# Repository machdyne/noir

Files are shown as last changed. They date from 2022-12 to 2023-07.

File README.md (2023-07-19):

# Noir Computer

Noir is an FPGA computer designed by Lone Dynamics Corporation.

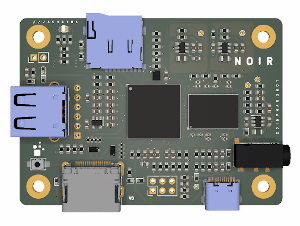
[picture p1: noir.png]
Noir Computer


This repo contains schematics, PCB layouts, pinouts, a 3D-printable case, example gateware and documentation.

Find more information on the [Noir product page](https://machdyne.com/product/noir-computer/).

## Dual-Core Bitstream

There is now a dual-core bitstream optimized for speed that significantly decreases boot time and adds a second RISC-V core.

In addition to updating to this bitstream (`images/v0/noir_dual.bit`), make sure you copy the `images/linux/noir_dual.dtb` file to the SD card and update `boot.json` to use `noir_dual.dtb`.

## Programming Noir

Noir has a JTAG interface and ships with a [DFU bootloader](https://github.com/machdyne/tinydfu-bootloader) that allows the included flash [MMOD](https://machdyne.com/product/mmod) to be programmed over the USB-C port.

### DFU

The DFU bootloader is available for 5 seconds after power-on, issuing a DFU command during this period will stop the boot process until the DFU device is detached. If no command is received the boot process will continue and the user gateware will be loaded.

Install [dfu-util](http://dfu-util.sourceforge.net) (Debian/Ubuntu):

```
$ sudo apt install dfu-util
```

Update the user gateware on the flash MMOD:

```
$ sudo dfu-util -a 0 -D image.bit
```

Detach the DFU device and continue the boot process:

```
$ sudo dfu-util -a 0 -e
```

It is possible to update the bootloader itself using DFU but you shouldn't attempt this unless you have a JTAG programmer (or another method to program the MMOD) available, in case you need to restore the bootloader.

### JTAG

These examples assume you're using a "USB Blaster" JTAG cable, see the header pinout below. You will need to have [openFPGALoader](https://github.com/trabucayre/openFPGALoader) installed.

Program the configuration SRAM:

```
openFPGALoader -c usb-blaster image.bit
```

Program the flash MMOD:

```
openFPGALoader -f -c usb-blaster images/bootloader/tinydfu_noir.bit
```

## Blinky 

Building the blinky example requires [Yosys](https://github.com/YosysHQ/yosys), [nextpnr-ecp5](https://github.com/YosysHQ/nextpnr) and [Project Trellis](https://github.com/YosysHQ/prjtrellis).

Assuming they are installed, you can simply type `make` to build the gateware, which will be written to output/blinky.bin. You can then use [openFPGALoader](https://github.com/trabucayre/openFPGALoader) or dfu-util to write the gateware to the device.

## Linux

See the [Kakao Linux](https://github.com/machdyne/kakao) repo for the latest instructions.

### Prebuilt Images

Copy the files from the `images/linux` directory to the root directory of a FAT-formatted MicroSD card.

Noir ships with LiteX gateware on the user gateware section of the MMOD that is compatible with these images. After several seconds the Linux penguin should appear on the screen (HDMI) followed by a login prompt.

### Building Linux

Please follow the setup instructions in the [linux-on-litex-vexriscv](https://github.com/litex-hub/linux-on-litex-vexriscv) repo and then:

1. Build the Linux-capable gateware:

```
$ cd linux-on-litex-vexriscv
$ ./make.py --board noir --uart-baudrate 115200 --build

$ ls build/noir
```

2. Write the gateware to the MMOD using USB DFU:

```
$ sudo dfu-util -a 0 -D build/noir/gateware/noir.bit
```

3. Copy the device tree binary `build/noir/noir.dtb` to a FAT-formatted MicroSD card.

4. Build the Linux kernel and root filesystem:

```
$ cd ..
$ git clone http://github.com/buildroot/buildroot
$ cd buildroot
$ make BR2_EXTERNAL=../linux-on-litex-vexriscv/buildroot/ litex_vexriscv_usbhost_defconfig
```

Optionally customize the kernel and buildroot packages:

```
$ make menuconfig
```

Build the kernel and rootfs:

```
$ make
$ ls output/images
```

5. Copy the `Image` and `rootfs.cpio` files from output/images to the MicroSD card.

6. Copy the OpenSBI binary (included in this repo as `noir/images/linux/opensbi.bin`) to the MicroSD card. Alternatively, you can build this binary by following [these instructions](https://github.com/litex-hub/linux-on-litex-vexriscv#-generating-the-opensbi-binary-optional).

7. Copy `noir/images/linux/boot.json` to the MicroSD card.

8. Power-cycle Noir. After Linux has finished booting you should see a login prompt on the HDMI display.

## LiteX

### Installing LiteX

If you haven't yet installed LiteX please see the [LiteX quick start guide](https://github.com/enjoy-digital/litex#quick-start-guide) for details on installing LiteX.

### Building Custom Gateware

Build the LiteX gateware:

```
$ cd litex-boards/litex_boards/targets
$ ./machdyne_noir.py --cpu-type=vexriscv --cpu-variant=lite --sys-clk-freq 40000000 --uart-baudrate 1000000 --uart-name serial --build
```

Program the LiteX gateware to SRAM over JTAG:

```
$ ./machdyne_noir.py --cable usb-blaster --load
```

Or program the LiteX gateware to flash over DFU:

```
$ sudo dfu-util -a 0 -D build/machdyne_noir/gateware/machdyne_noir.bit
```

## JTAG Header

The 3.3V JTAG header can be used to program the FPGA SRAM as well as the MMOD flash memory. It can also be used to provide power (5V) to the board.

```
1 2
3 4
5 6
```

| Pin | Signal |
| --- | --- |
| 1 | TCK |
| 2 | TDI |
| 3 | TDO |
| 4 | TMS |
| 5 | 5V0 |
| 6 | GND |

## Resources

 * [fpga-dac audio player](https://github.com/machdyne/fpga-dac)

## Board Revisions

| Revision | Notes |
| --- | ----- |
| V0 | Initial version |
| V1 | Work in progress; adds composite video DAC output to 3.5mm jack |

## License

The contents of this repo are released under the [Lone Dynamics Open License](LICENSE.md) with the following exceptions:

- The KiCad design files contain parts of the [kicad-pmod](https://github.com/mithro/kicad-pmod) library which is released under the [Apache License, Version 2.0](https://www.apache.org/licenses/LICENSE-2.0.html).

- The KiCad design files may contain symbols and footprints released under other licenses; please contact us if we've failed to give proper attribution.

Note: You can use these designs for commercial purposes but we ask that instead of producing exact clones, that you either replace our trademarks and logos with your own or add your own next to ours.

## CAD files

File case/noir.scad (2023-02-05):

/*
 * Noir Case
 * Copyright (c) 2022 Lone Dynamics Corporation. All rights reserved.
 *
 * required hardware:
 *  - 4 x M3 x 18mm countersunk bolts
 *  - 4 x M3 nuts
 *
 */

$fn = 100;

board_width = 50;
board_thickness = 1.5;
board_length = 70;
board_height = 1.6;
board_spacing = 2;

wall = 1.5;

top_height = 10;
bottom_height = 8.5;

mdn_board();

translate([0,0,15])
	mdn_case_top();

translate([0,0,-15])
	mdn_case_bottom();

module mdn_board() {
	
	difference() {
		color([0,0.5,0])
			roundedcube(board_width,board_length,board_thickness,3);
		translate([5, 5, -1]) cylinder(d=3.2, h=10);
		translate([5, 65, -1]) cylinder(d=3.2, h=10);
		translate([45, 5, -1]) cylinder(d=3.2, h=10);
		translate([45, 65, -1]) cylinder(d=3.2, h=10);
	}	
	
}

module mdn_case_top() {
	
	difference() {
				
		color([0.5,0.5,0.5])
			roundedcube(board_width+(wall*2),board_length+(wall*2),top_height,2.5);

		// cutouts
			
		translate([2,9.5,-2])
			roundedcube(board_width-1.25,board_length-16,10.25,2.5);

		translate([9.5,3,-2])
			roundedcube(board_width-16,board_length-3,10.25,2.5);
		
		// led vent
		translate([-1,board_length-59,3.5])
			cube([board_width-10,1.5,1.5]);
	
		translate([wall, wall, 0]) {

			// vents
			translate([50/2-(20/2),60,0]) cube([20,1,20]);
			translate([50/2-(20/2),55,0]) cube([20,1,20]);
			translate([50/2-(20/2),50,0]) cube([20,1,20]);
			
			// HDMI
			translate([30,19.55-(15.5/2),-1]) cube([30,15.5,6.2+1]);
		
			// USBA
			translate([25-(15/2),-5,-1]) cube([15,30,7.2+1]);

			// USBC
			translate([30,53.8-(9.5/2),-1]) cube([30,9.5,3.5+1]);
		
			// SD
			translate([-5,25.3-(15/2),-1]) cube([30,15,2+1]);

			// USBA
			translate([36.5-(6.2/2),65,-1]) cube([6.2,30,5+1]);
			
			// bolt holes
			translate([5, 5, -21]) cylinder(d=3.5, h=40);
			translate([5, 65, -21]) cylinder(d=3.5, h=40);
			translate([45, 5, -20]) cylinder(d=3.5, h=40);
			translate([45, 65, -21]) cylinder(d=3.5, h=40);

			// flush mount bolt holes
			translate([5, 5, top_height-1.5]) cylinder(d=5.25, h=4);
			translate([5, 65, top_height-1.5]) cylinder(d=5.25, h=4);
			translate([45, 5, top_height-1.5]) cylinder(d=5.25, h=4);
			translate([45, 65, top_height-1.5]) cylinder(d=5.25, h=4);

			// noir text
			rotate(270)
				translate([-22.5,25-3,top_height-0.5])
					linear_extrude(1)
						text("N   O   I   R", size=5, halign="center",
							font="Ubuntu:style=Bold");

		}
		
	}	
}

module mdn_case_bottom() {
	
	difference() {
		color([0.5,0.5,0.5])
			roundedcube(board_width+(wall*2),board_length+(wall*2),bottom_height,2.5);
		
		// cutouts
		translate([3,10,1.5])
			roundedcube(board_width-3,board_length-17,10,2.5);
				
		translate([10.5,2.5,1.5])
			roundedcube(board_width-17.5,board_length-2,10,2.5);

		translate([wall, wall, 0]) {
			
		// board cutout
		translate([0,0,bottom_height-board_height])
			roundedcube(board_width+0.2,board_length+0.2,board_height+1,2.5);

		translate([wall, wall, 0]) {

			// USBC
			translate([38.5,53.8-(9.5/2),5]) cube([10,9.5,10.5+1]);
			
		}

		// bolt holes
		translate([5, 5, -11]) cylinder(d=3.2, h=25);
		translate([5, 65, -11]) cylinder(d=3.2, h=25);
		translate([45, 5, -11]) cylinder(d=3.2, h=25);
		translate([45, 65, -11]) cylinder(d=3.2, h=25);

		// nut holes
		translate([5, 5, -1]) cylinder(d=7, h=4, $fn=6);
		translate([5, 65, -1]) cylinder(d=7, h=4, $fn=6);
		translate([45, 5, -1]) cylinder(d=7, h=4, $fn=6);
		translate([45, 65, -1]) cylinder(d=7, h=4, $fn=6);

		}
		
	}	
}

// https://gist.github.com/tinkerology/ae257c5340a33ee2f149ff3ae97d9826
module roundedcube(xx, yy, height, radius)
{
    translate([0,0,height/2])
    hull()
    {
        translate([radius,radius,0])
        cylinder(height,radius,radius,true);

        translate([xx-radius,radius,0])
        cylinder(height,radius,radius,true);

        translate([xx-radius,yy-radius,0])
        cylinder(height,radius,radius,true);

        translate([radius,yy-radius,0])
        cylinder(height,radius,radius,true);
    }
}

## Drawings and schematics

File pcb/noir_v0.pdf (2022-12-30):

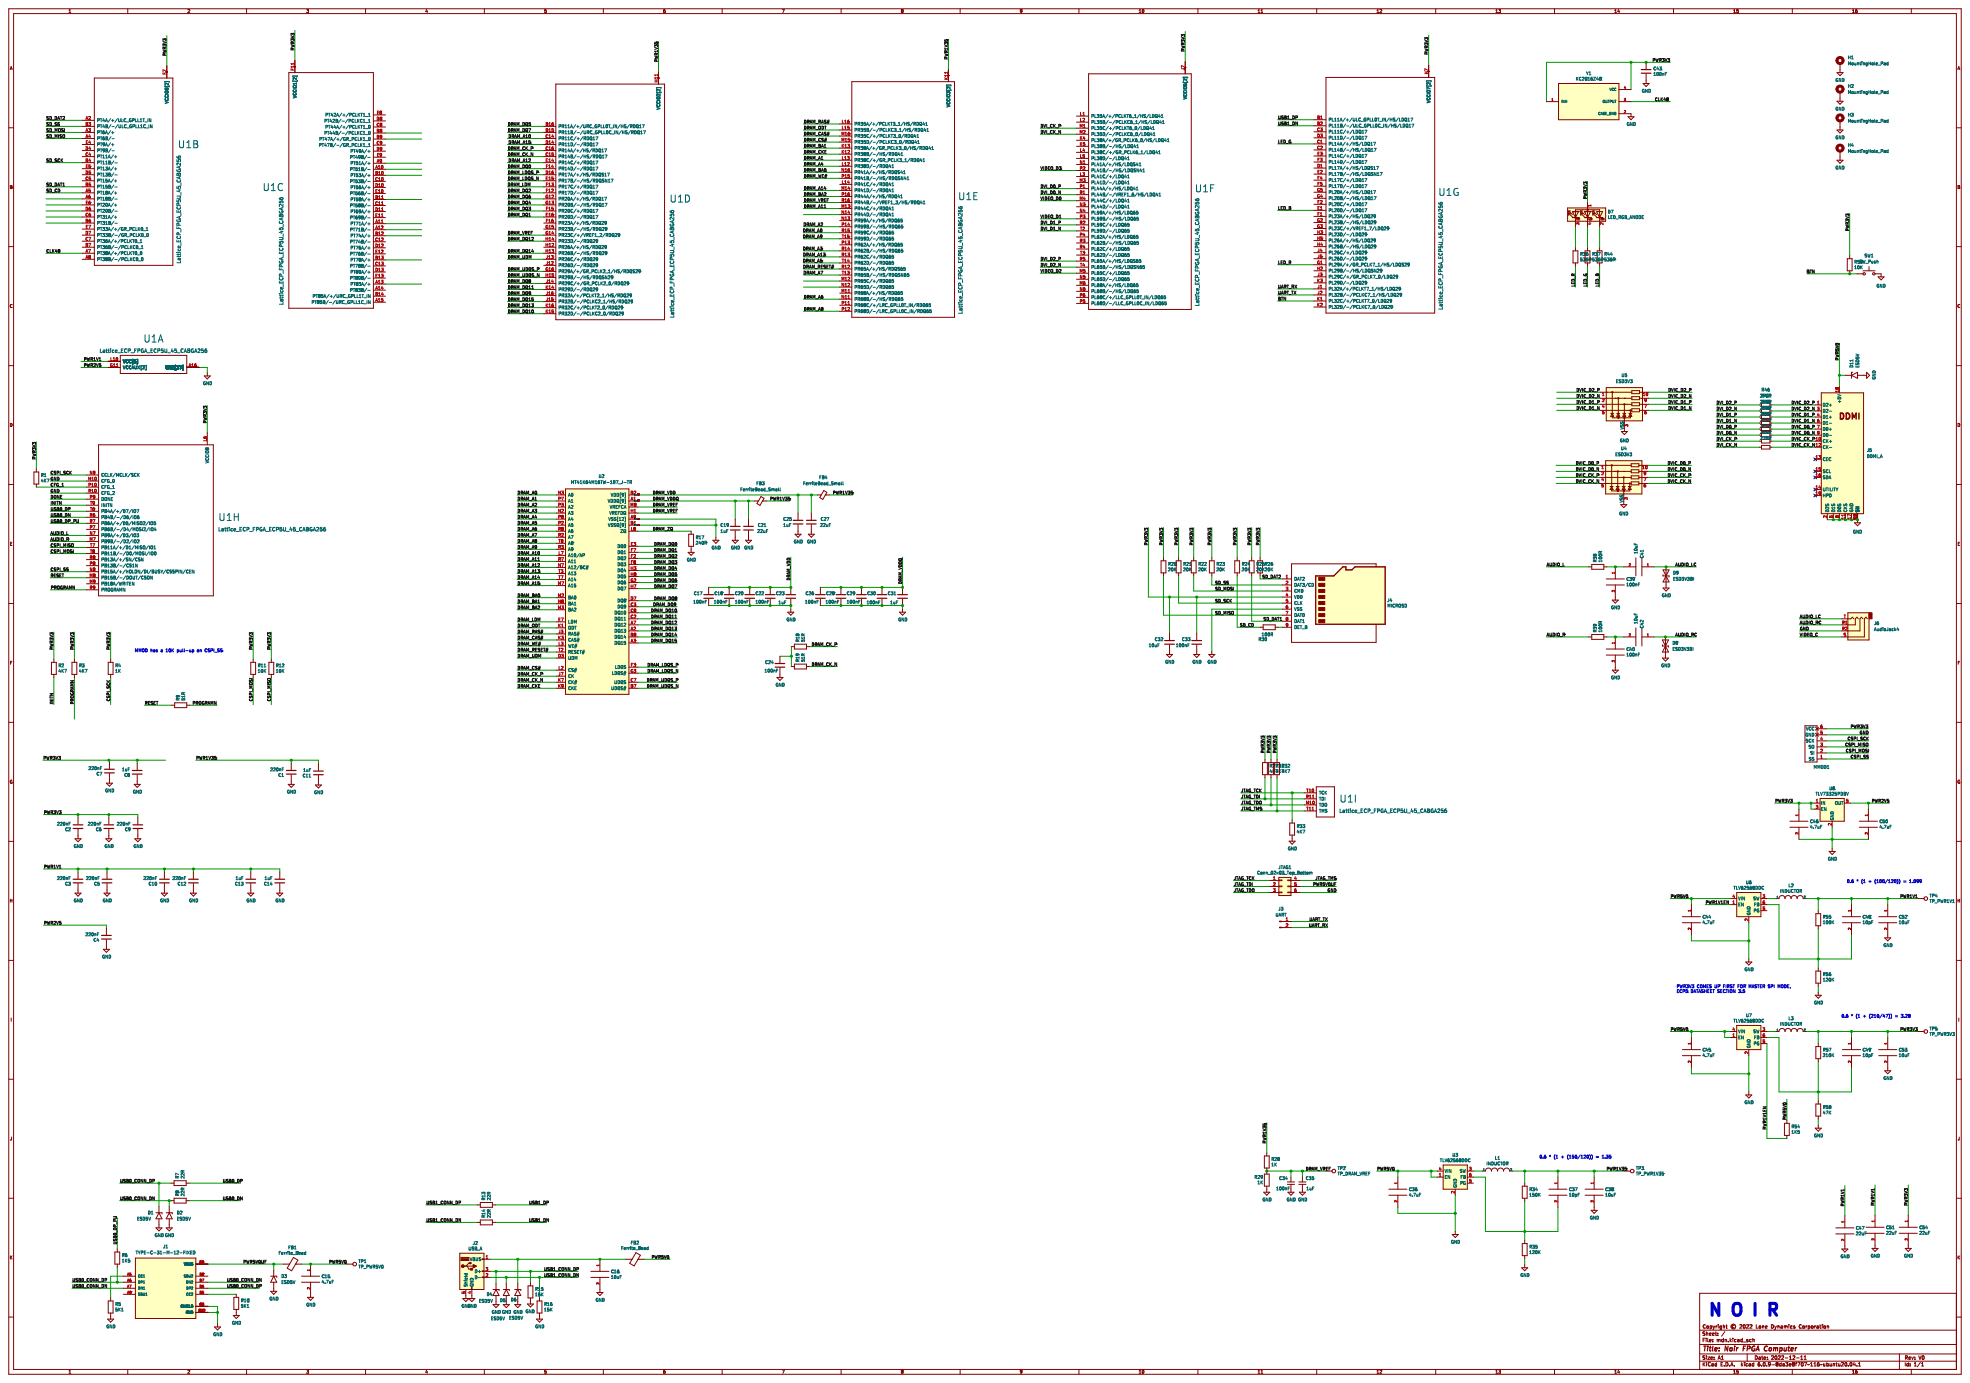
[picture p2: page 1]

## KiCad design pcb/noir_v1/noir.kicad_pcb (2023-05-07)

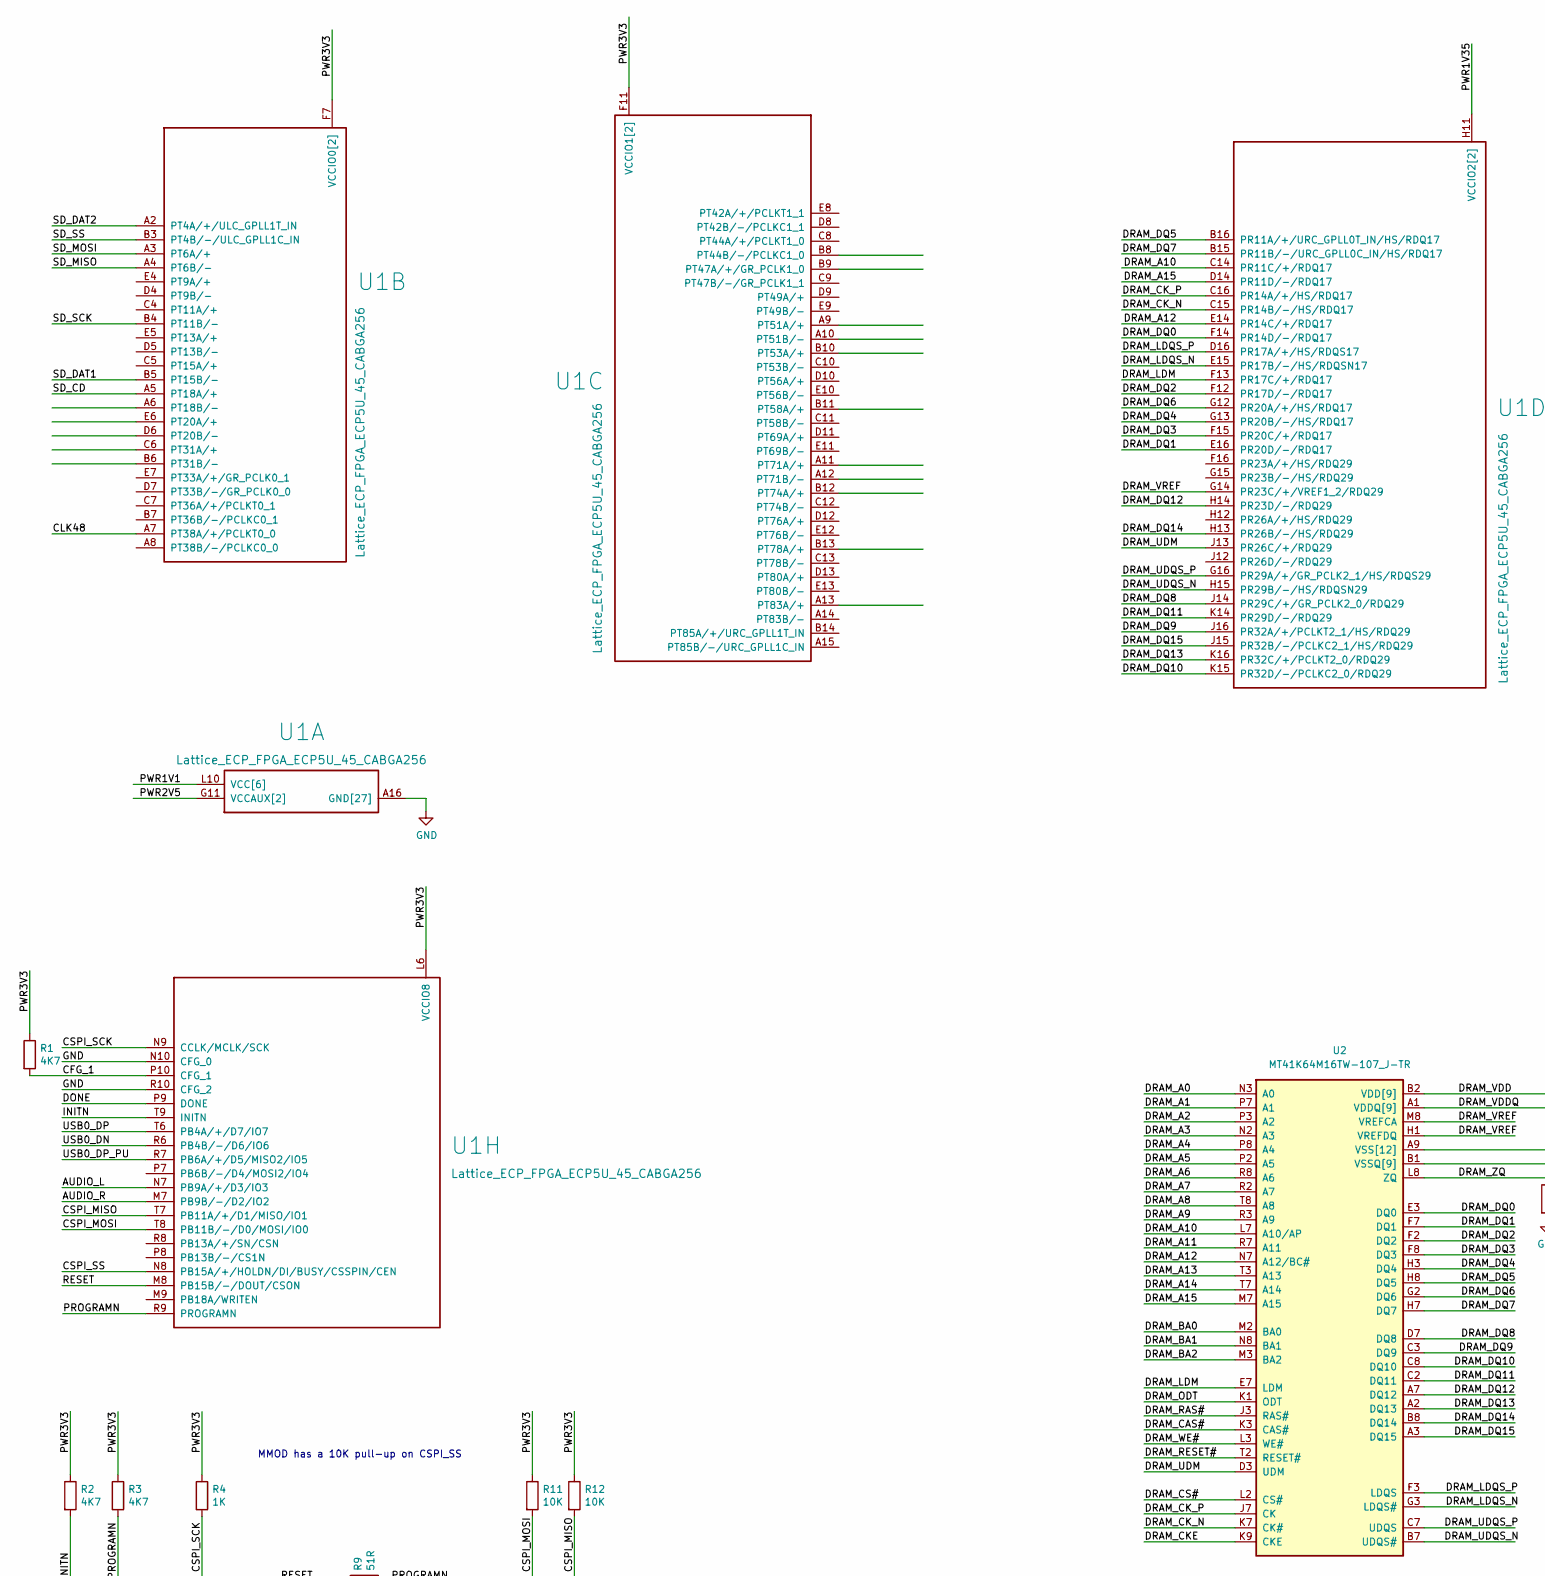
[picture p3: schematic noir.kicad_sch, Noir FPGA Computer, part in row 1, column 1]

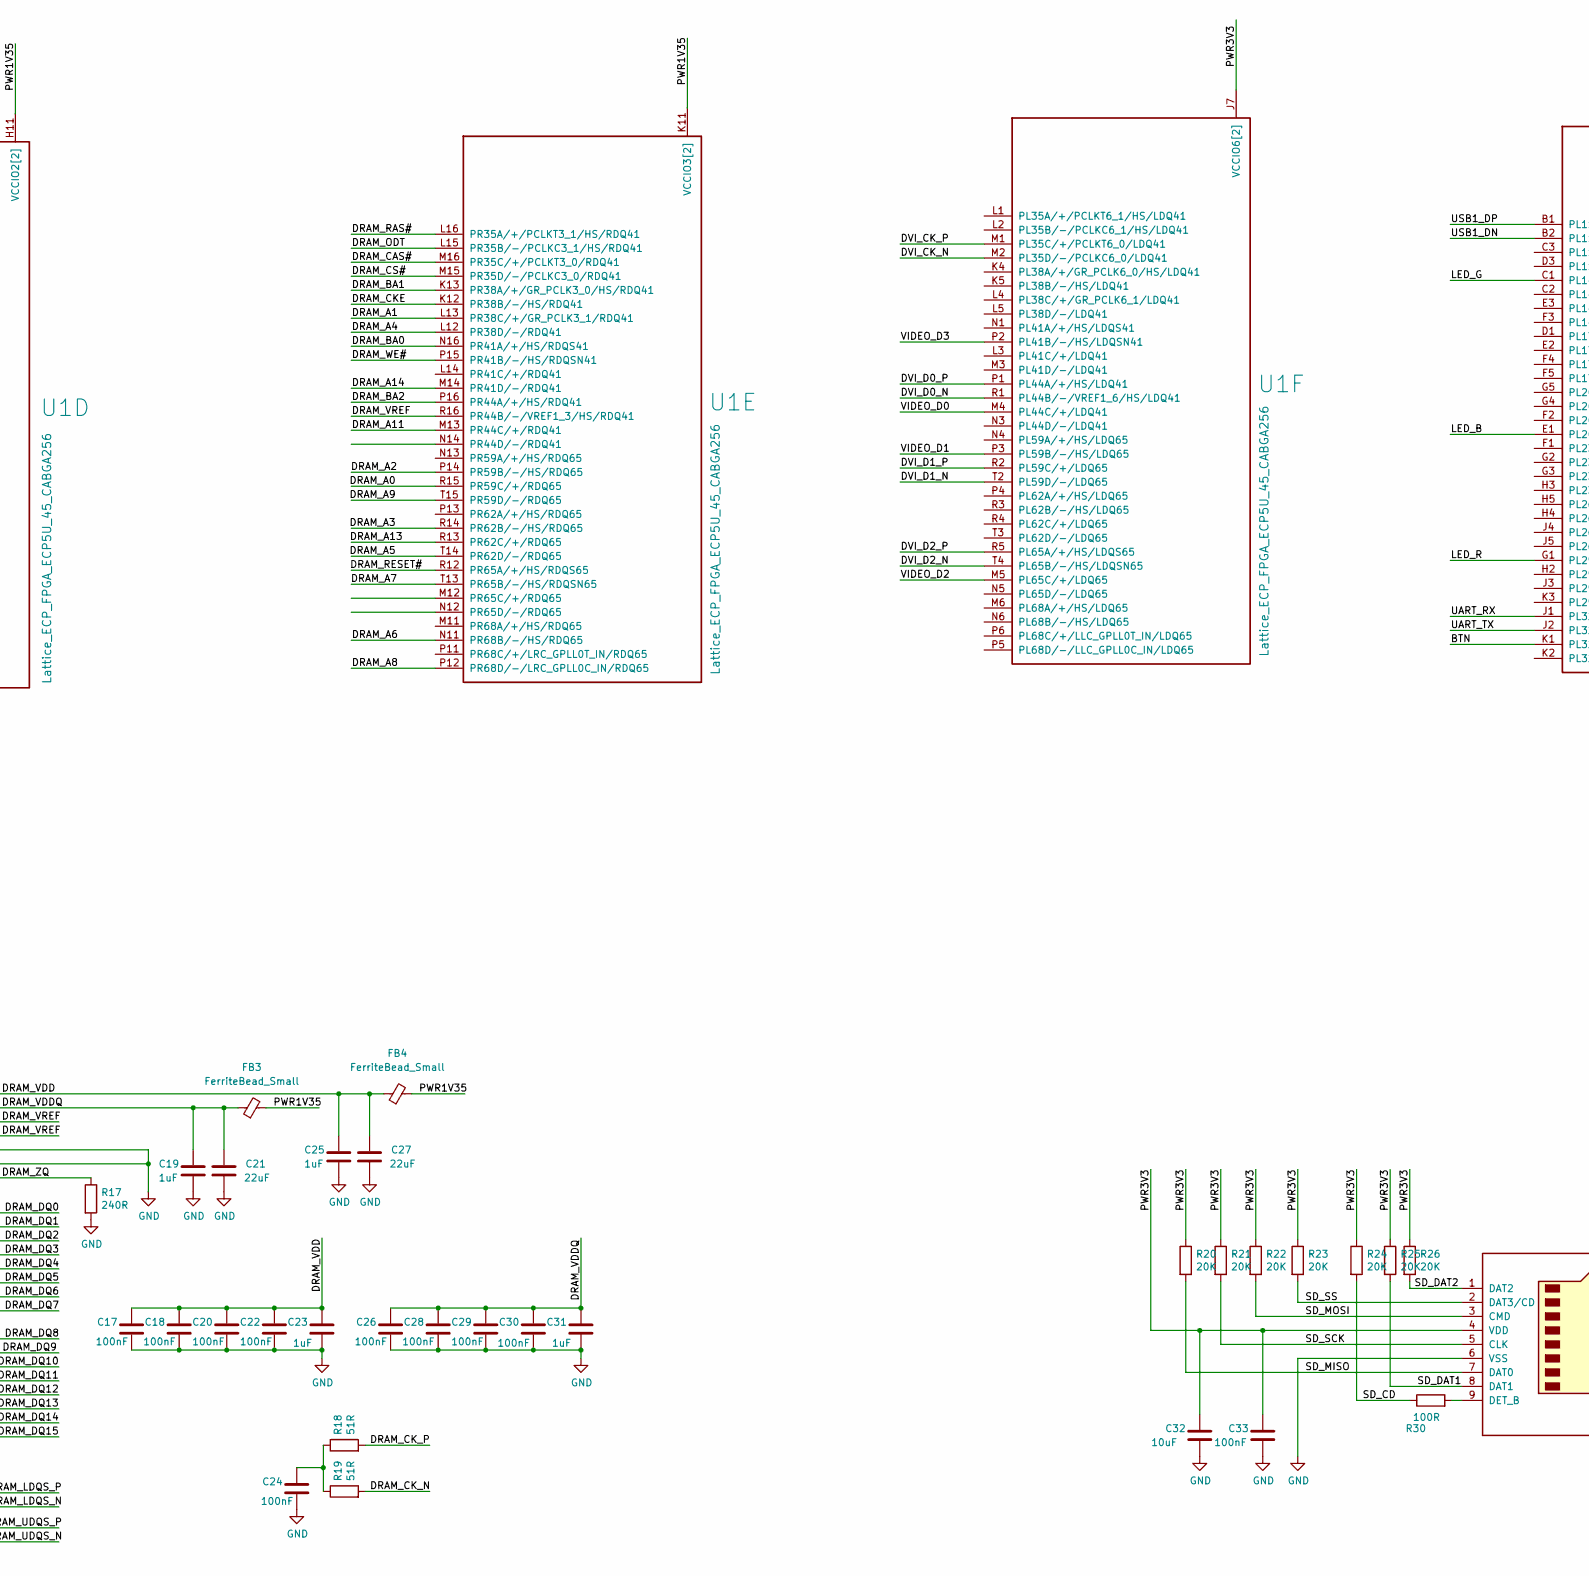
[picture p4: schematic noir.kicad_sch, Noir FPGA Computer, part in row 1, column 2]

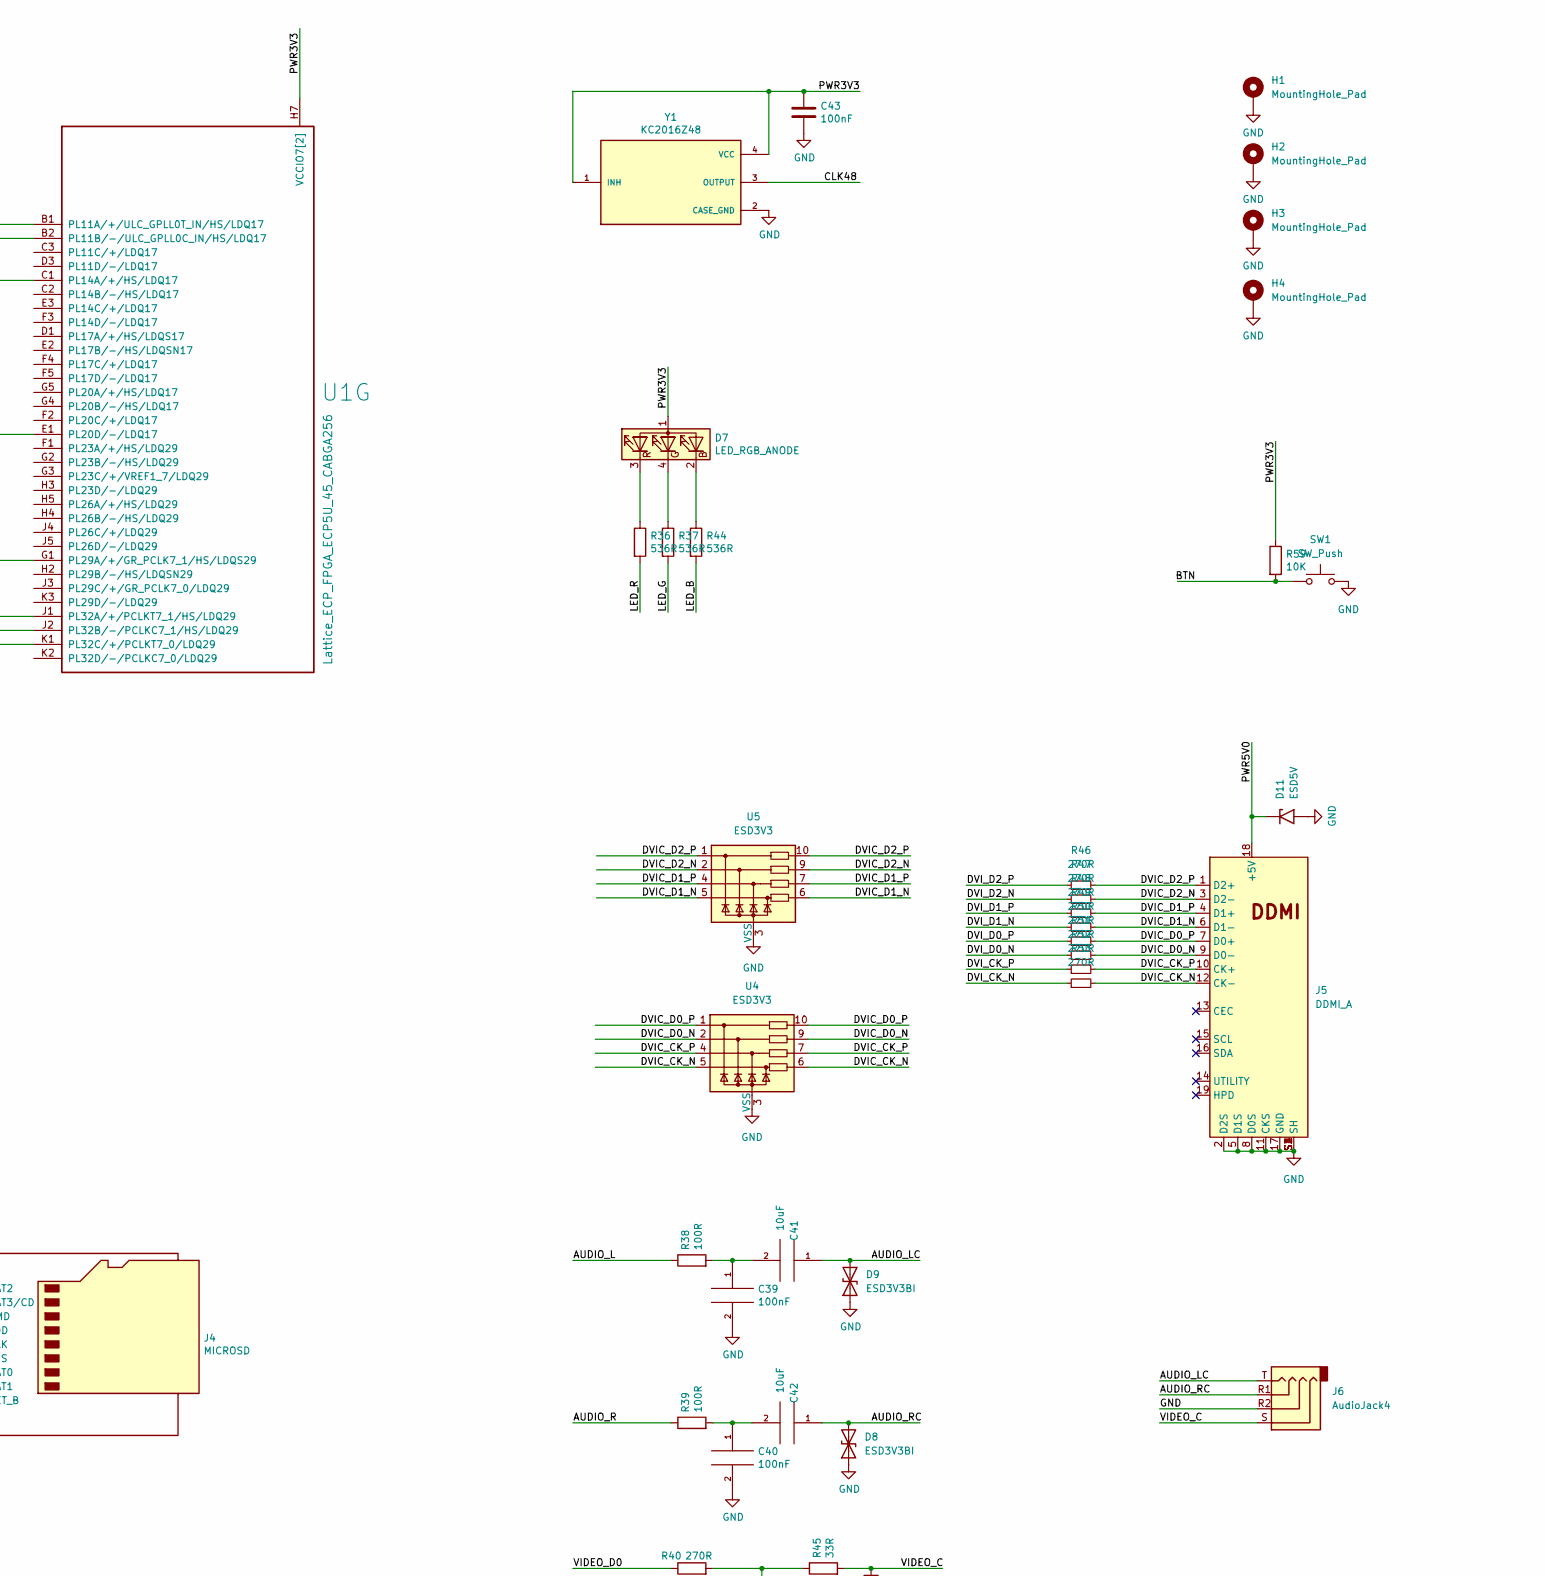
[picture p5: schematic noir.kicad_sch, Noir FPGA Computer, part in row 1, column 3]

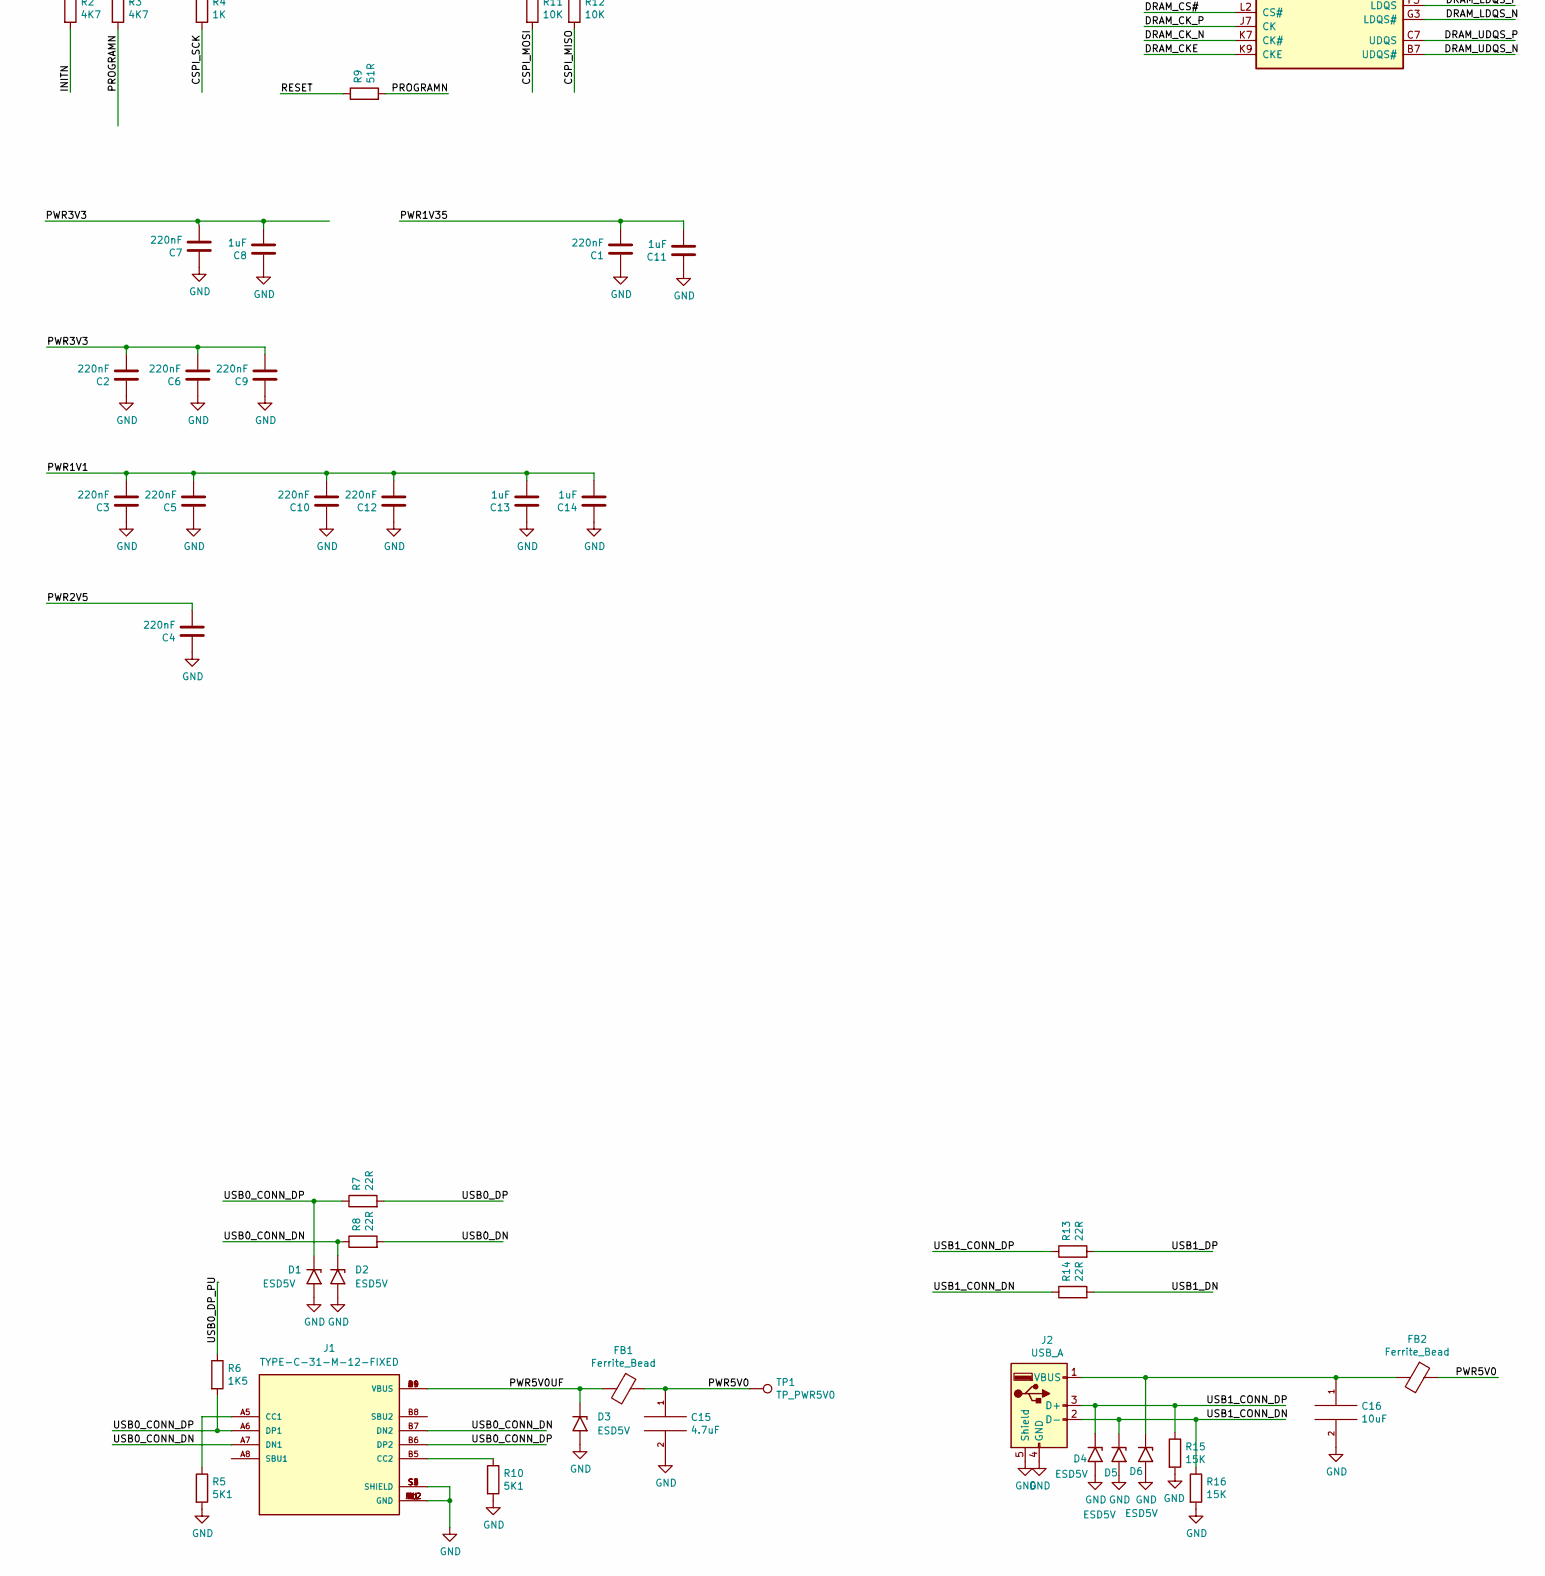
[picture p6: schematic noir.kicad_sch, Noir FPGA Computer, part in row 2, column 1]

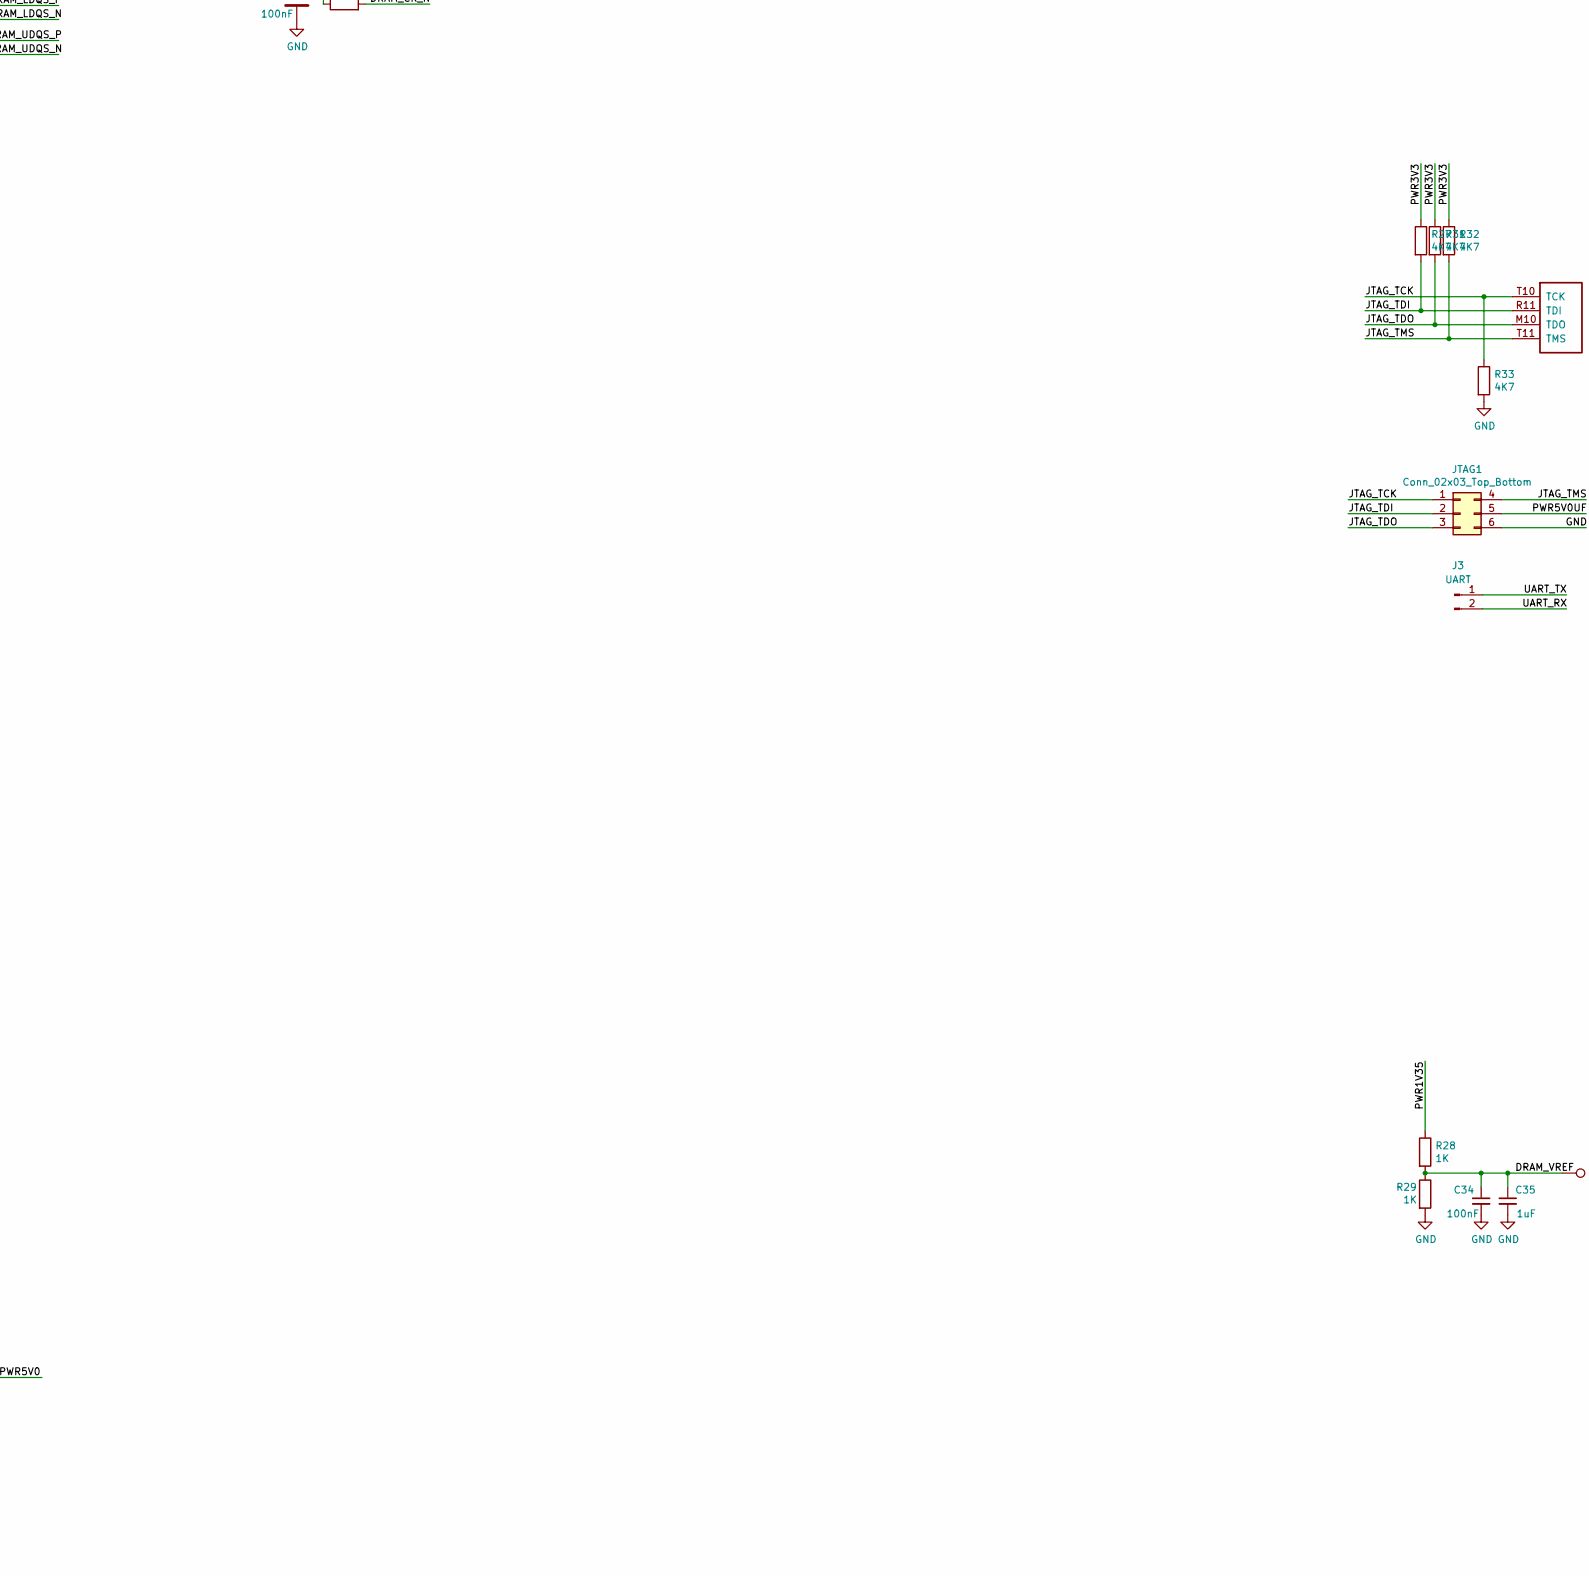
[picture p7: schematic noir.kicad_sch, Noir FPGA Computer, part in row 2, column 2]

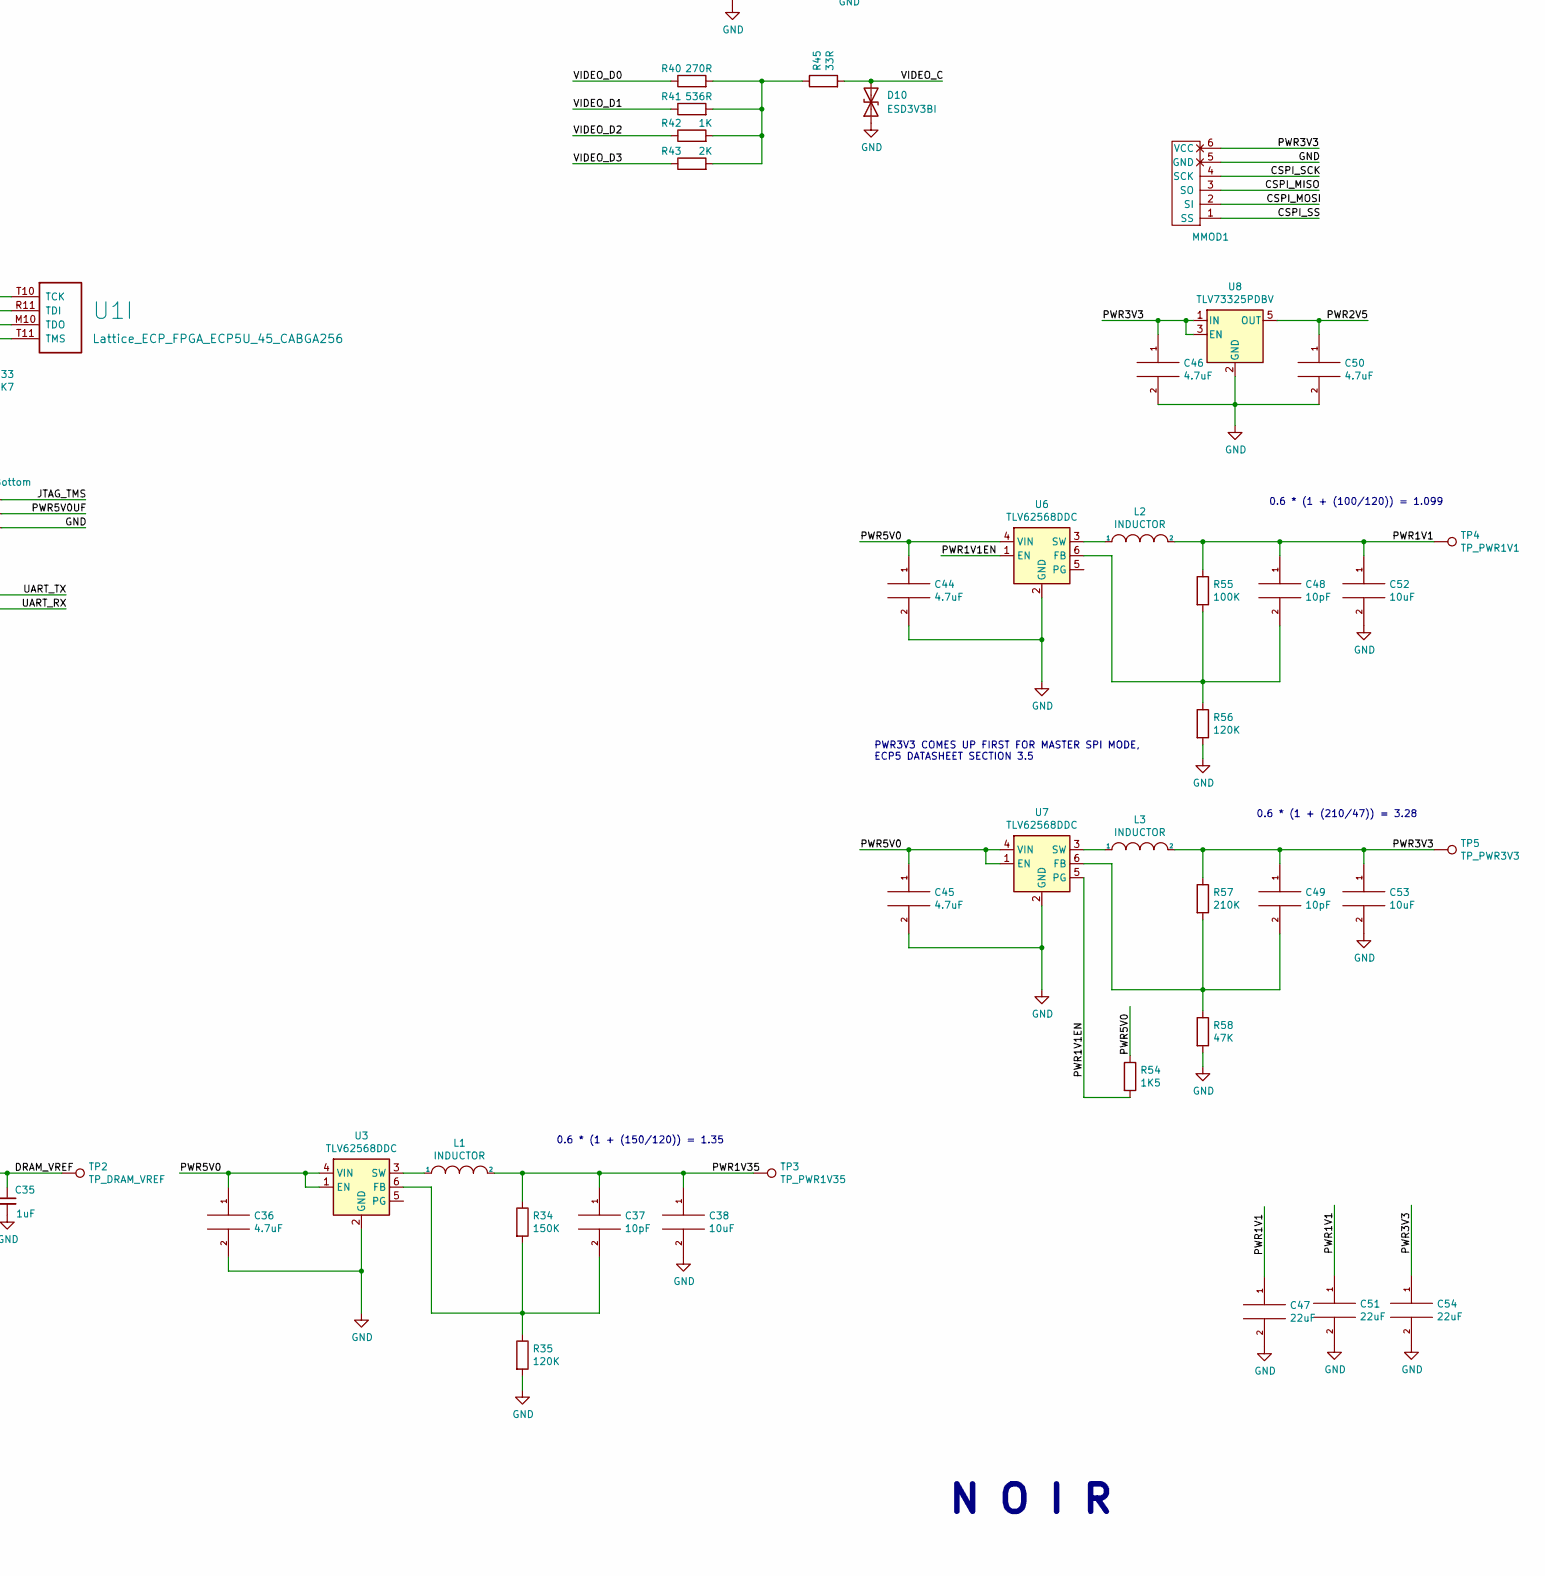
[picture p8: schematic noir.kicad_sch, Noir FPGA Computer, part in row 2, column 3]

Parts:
C1, C2, C3, C4, C5, C6, C7, C9, C10, C12: 220nF; C_0603_1608Metric
C8, C11, C13, C14, C35: 1uF; C_0603_1608Metric
C15, C36, C44, C45, C46, C50: 4.7uF; C_0603_1608Metric
C16, C38, C41, C42, C52, C53: 10uF; C_0603_1608Metric
C17, C18, C20, C22, C26, C28, C29, C30: 100nF; C_0402_1005Metric
C19, C23, C25, C31: 1uF; C_0402_1005Metric
C21, C27: 22uF; R_0603_1608Metric
C24, C33, C43: 100nF; R_0603_1608Metric
C32: 10uF; R_0603_1608Metric
C34, C39, C40: 100nF; C_0603_1608Metric
C37, C48, C49: 10pF; C_0603_1608Metric
C47, C51, C54: 22uF; C_0603_1608Metric
D1, D2, D3, D4, D5, D6, D11: ESD5V; D_SOD-523
D7: LED_RGB_ANODE; LED_RGB_0606_CHANZON
D8, D9, D10: ESD3V3BI; D_SOD-523
FB1, FB2: Ferrite_Bead; R_0603_1608Metric
FB3, FB4: FerriteBead_Small; R_0603_1608Metric
H1, H2, H3, H4: MountingHole_Pad; MountingHole_3.2mm_M3_Pad
J1: TYPE-C-31-M-12-FIXED; USB_C_Receptacle_HRO_TYPE-C-31-M-12-BIG-PADS; PARTREV A
J2: USB_A; USB_A_Stewart_SS-52100-001_Horizontal
J3: UART; PinHeader_1x02_P2.54mm_Vertical
J4: MICROSD; SDCARD
J5: DDMI_A; HDMI_TE_1827059-3-FIXED
J6: AudioJack4; Jack_3.5mm_PJ320D_Horizontal
JTAG1: Conn_02x03_Top_Bottom; PinHeader_2x03_P2.54mm_Vertical
L1, L2, L3: INDUCTOR; L_0805_2012Metric
MMOD1: PMOD-Device-x1-Type-2-SPI; MMOD_Host_Socket
R1, R2, R3, R27, R31, R32, R33: 4K7; R_0603_1608Metric
R4, R28, R29, R42: 1K; R_0603_1608Metric
R5, R10: 5K1; R_0603_1608Metric
R6, R54: 1K5; R_0603_1608Metric
R7, R8, R13, R14: 22R; R_0603_1608Metric
R9, R18, R19: 51R; R_0603_1608Metric
R11, R12, R59: 10K; R_0603_1608Metric
R15, R16: 15K; R_0603_1608Metric
R17: 240R; R_0603_1608Metric
R20, R21, R22, R23, R24, R25, R26: 20K; R_0603_1608Metric
R30, R38, R39: 100R; R_0603_1608Metric
R34: 150K; R_0603_1608Metric
R35, R56: 120K; R_0603_1608Metric
R36, R37, R41, R44: 536R; R_0603_1608Metric
R40: 270R; R_0603_1608Metric
R43: 2K; R_0603_1608Metric
R45: 33R; R_0603_1608Metric
R46, R47, R48, R49, R50, R51, R52, R53: 270R; R_0402_1005Metric
R55: 100K; R_0603_1608Metric
R57: 210K; R_0603_1608Metric
R58: 47K; R_0603_1608Metric
SW1: SW_Push; Button_2P_3x4mm
TP1: TP_PWR5V0; TestPoint_THTPad_D1.0mm_Drill0.5mm
TP2: TP_DRAM_VREF; TestPoint_THTPad_D1.0mm_Drill0.5mm
TP3: TP_PWR1V35; TestPoint_THTPad_D1.0mm_Drill0.5mm
TP4: TP_PWR1V1; TestPoint_THTPad_D1.0mm_Drill0.5mm
TP5: TP_PWR3V3; TestPoint_THTPad_D1.0mm_Drill0.5mm
U1: Lattice_ECP_FPGA_ECP5U_45_CABGA256; BGA-256_14.0x14.0mm_Layout16x16_P0.8mm_Ball0.45mm_Pad0.32mm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
U2: MT41K64M16TW-107_J-TR; BGA-96_9.0x13.0mm_Layout2x3x16_P0.8mm
U3, U6, U7: TLV62568DDC; SOT-23-6
U4, U5: ESD3V3; Diodes_UDFN-10_1.0x2.5mm_P0.5mm
U8: TLV73325PDBV; SOT-23-5
Y1: KC2016Z48; OSC_KC2016Z13.5600C1KX00; PARTREV November 2020

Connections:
/AUDIO_L: R38.1, U1.N7 (PB9A/+/D3/IO3)
/AUDIO_LC: C41.1, D9.2 (A2), J6.T
/AUDIO_R: R39.1, U1.M7 (PB9B/-/D2/IO2)
/AUDIO_RC: C42.1, D8.2 (A2), J6.R1
/BTN: R59.2, SW1.1, U1.K1 (PL32C/+/PCLKT7_0/LDQ29)
/CFG_1: R1.2, U1.P10 (CFG_1)
/CLK48: U1.A7 (PT38A/+/PCLKT0_0), Y1.3 (OUTPUT)
/CSPI_MISO: MMOD1.3 (SO), R12.2, U1.T7 (PB11A/+/D1/MISO/IO1)
/CSPI_MOSI: MMOD1.2 (SI), R11.2, U1.T8 (PB11B/-/D0/MOSI/IO0)
/CSPI_SCK: MMOD1.4 (SCK), R4.2, U1.N9 (CCLK/MCLK/SCK)
/CSPI_SS: MMOD1.1 (SS), U1.N8 (PB15A/+/HOLDN/DI/BUSY/CSSPIN/CEN)
/DONE: U1.P9 (DONE)
/DRAM_A0: U1.R15 (PR59C/+/RDQ65), U2.N3 (A0)
/DRAM_A1: U1.L13 (PR38C/+/GR_PCLK3_1/RDQ41), U2.P7 (A1)
/DRAM_A2: U1.P14 (PR59B/-/HS/RDQ65), U2.P3 (A2)
/DRAM_A3: U1.R14 (PR62B/-/HS/RDQ65), U2.N2 (A3)
/DRAM_A4: U1.L12 (PR38D/-/RDQ41), U2.P8 (A4)
/DRAM_A5: U1.T14 (PR62D/-/RDQ65), U2.P2 (A5)
/DRAM_A6: U1.N11 (PR68B/-/HS/RDQ65), U2.R8 (A6)
/DRAM_A7: U1.T13 (PR65B/-/HS/RDQSN65), U2.R2 (A7)
/DRAM_A8: U1.P12 (PR68D/-/LRC_GPLL0C_IN/RDQ65), U2.T8 (A8)
/DRAM_A9: U1.T15 (PR59D/-/RDQ65), U2.R3 (A9)
/DRAM_A10: U1.C14 (PR11C/+/RDQ17), U2.L7 (A10/AP)
/DRAM_A11: U1.M13 (PR44C/+/RDQ41), U2.R7 (A11)
/DRAM_A12: U1.E14 (PR14C/+/RDQ17), U2.N7 (A12/BC#)
/DRAM_A13: U1.R13 (PR62C/+/RDQ65), U2.T3 (A13)
/DRAM_A14: U1.M14 (PR41D/-/RDQ41), U2.T7 (A14)
/DRAM_A15: U1.D14 (PR11D/-/RDQ17), U2.M7 (A15)
/DRAM_BA0: U1.N16 (PR41A/+/HS/RDQS41), U2.M2 (BA0)
/DRAM_BA1: U1.K13 (PR38A/+/GR_PCLK3_0/HS/RDQ41), U2.N8 (BA1)
/DRAM_BA2: U1.P16 (PR44A/+/HS/RDQ41), U2.M3 (BA2)
/DRAM_CAS#: U1.M16 (PR35C/+/PCLKT3_0/RDQ41), U2.K3 (CAS#)
/DRAM_CKE: U1.K12 (PR38B/-/HS/RDQ41), U2.K9 (CKE)
/DRAM_CK_N: R19.2, U1.C15 (PR14B/-/HS/RDQ17), U2.K7 (CK#)
/DRAM_CK_P: R18.2, U1.C16 (PR14A/+/HS/RDQ17), U2.J7 (CK)
/DRAM_CS#: U1.M15 (PR35D/-/PCLKC3_0/RDQ41), U2.L2 (CS#)
/DRAM_DQ0: U1.F14 (PR14D/-/RDQ17), U2.E3 (DQ0)
/DRAM_DQ1: U1.E16 (PR20D/-/RDQ17), U2.F7 (DQ1)
/DRAM_DQ2: U1.F12 (PR17D/-/RDQ17), U2.F2 (DQ2)
/DRAM_DQ3: U1.F15 (PR20C/+/RDQ17), U2.F8 (DQ3)
/DRAM_DQ4: U1.G13 (PR20B/-/HS/RDQ17), U2.H3 (DQ4)
/DRAM_DQ5: U1.B16 (PR11A/+/URC_GPLL0T_IN/HS/RDQ17), U2.H8 (DQ5)
/DRAM_DQ6: U1.G12 (PR20A/+/HS/RDQ17), U2.G2 (DQ6)
/DRAM_DQ7: U1.B15 (PR11B/-/URC_GPLL0C_IN/HS/RDQ17), U2.H7 (DQ7)
/DRAM_DQ8: U1.J14 (PR29C/+/GR_PCLK2_0/RDQ29), U2.D7 (DQ8)
/DRAM_DQ9: U1.J16 (PR32A/+/PCLKT2_1/HS/RDQ29), U2.C3 (DQ9)
/DRAM_DQ10: U1.K15 (PR32D/-/PCLKC2_0/RDQ29), U2.C8 (DQ10)
/DRAM_DQ11: U1.K14 (PR29D/-/RDQ29), U2.C2 (DQ11)
/DRAM_DQ12: U1.H14 (PR23D/-/RDQ29), U2.A7 (DQ12)
/DRAM_DQ13: U1.K16 (PR32C/+/PCLKT2_0/RDQ29), U2.A2 (DQ13)
/DRAM_DQ14: U1.H13 (PR26B/-/HS/RDQ29), U2.B8 (DQ14)
/DRAM_DQ15: U1.J15 (PR32B/-/PCLKC2_1/HS/RDQ29), U2.A3 (DQ15)
/DRAM_LDM: U1.F13 (PR17C/+/RDQ17), U2.E7 (LDM)
/DRAM_LDQS_N: U1.E15 (PR17B/-/HS/RDQSN17), U2.G3 (LDQS#)
/DRAM_LDQS_P: U1.D16 (PR17A/+/HS/RDQS17), U2.F3 (LDQS)
/DRAM_ODT: U1.L15 (PR35B/-/PCLKC3_1/HS/RDQ41), U2.K1 (ODT)
/DRAM_RAS#: U1.L16 (PR35A/+/PCLKT3_1/HS/RDQ41), U2.J3 (RAS#)
/DRAM_RESET#: U1.R12 (PR65A/+/HS/RDQS65), U2.T2 (RESET#)
/DRAM_UDM: U1.J13 (PR26C/+/RDQ29), U2.D3 (UDM)
/DRAM_UDQS_N: U1.H15 (PR29B/-/HS/RDQSN29), U2.B7 (UDQS#)
/DRAM_UDQS_P: U1.G16 (PR29A/+/GR_PCLK2_1/HS/RDQS29), U2.C7 (UDQS)
/DRAM_VDD: C17.1, C18.1, C20.1, C22.1, C23.1, C25.1, C27.1, FB4.1, U2.B2 (VDD[9]), U2.D9 (VDD), U2.G7 (VDD), U2.K2 (VDD), U2.K8 (VDD), U2.N1 (VDD), U2.N9 (VDD), U2.R1 (VDD), U2.R9 (VDD)
/DRAM_VDDQ: C19.1, C21.1, C26.1, C28.1, C29.1, C30.1, C31.1, FB3.1, U2.A1 (VDDQ[9]), U2.A8 (VDDQ), U2.C1 (VDDQ), U2.C9 (VDDQ), U2.D2 (VDDQ), U2.E9 (VDDQ), U2.F1 (VDDQ), U2.H2 (VDDQ), U2.H9 (VDDQ)
/DRAM_VREF: C34.1, C35.1, R28.2, R29.1, TP2.1, U1.G14 (PR23C/+/VREF1_2/RDQ29), U1.R16 (PR44B/-/VREF1_3/HS/RDQ41), U2.H1 (VREFDQ), U2.M8 (VREFCA)
/DRAM_WE#: U1.P15 (PR41B/-/HS/RDQSN41), U2.L3 (WE#)
/DRAM_ZQ: R17.1, U2.L8 (ZQ)
/DVIC_CK_N: J5.12 (CK-), R53.2, U4.5, U4.6
/DVIC_CK_P: J5.10 (CK+), R52.2, U4.4, U4.7
/DVIC_D0_N: J5.9 (D0-), R51.2, U4.2, U4.9
/DVIC_D0_P: J5.7 (D0+), R50.2, U4.1, U4.10
/DVIC_D1_N: J5.6 (D1-), R49.2, U5.5, U5.6
/DVIC_D1_P: J5.4 (D1+), R48.2, U5.4, U5.7
/DVIC_D2_N: J5.3 (D2-), R47.2, U5.2, U5.9
/DVIC_D2_P: J5.1 (D2+), R46.2, U5.1, U5.10
/DVI_CK_N: R53.1, U1.M2 (PL35D/-/PCLKC6_0/LDQ41)
/DVI_CK_P: R52.1, U1.M1 (PL35C/+/PCLKT6_0/LDQ41)
/DVI_D0_N: R51.1, U1.R1 (PL44B/-/VREF1_6/HS/LDQ41)
/DVI_D0_P: R50.1, U1.P1 (PL44A/+/HS/LDQ41)
/DVI_D1_N: R49.1, U1.T2 (PL59D/-/LDQ65)
/DVI_D1_P: R48.1, U1.R2 (PL59C/+/LDQ65)
/DVI_D2_N: R47.1, U1.T4 (PL65B/-/HS/LDQSN65)
/DVI_D2_P: R46.1, U1.R5 (PL65A/+/HS/LDQS65)
/INITN: R2.2, U1.T9 (INITN)
/JTAG_TCK: JTAG1.1, R33.1, U1.T10 (TCK)
/JTAG_TDI: JTAG1.2, R27.2, U1.R11 (TDI)
/JTAG_TDO: JTAG1.3, R31.2, U1.M10 (TDO)
/JTAG_TMS: JTAG1.4, R32.2, U1.T11 (TMS)
/LED_B: R44.2, U1.E1 (PL20D/-/LDQ17)
/LED_G: R37.2, U1.C1 (PL14A/+/HS/LDQ17)
/LED_R: R36.2, U1.G1 (PL29A/+/GR_PCLK7_1/HS/LDQS29)
/PROGRAMN: R3.2, R9.2, U1.R9 (PROGRAMN)
/PWR1V1: C3.2, C5.2, C10.2, C12.2, C13.2, C14.2, C47.1, C48.1, C51.1, C52.1, L2.2, R55.1, TP4.1, U1.G6 (VCC[6]), U1.G7 (VCC[6]), U1.G9 (VCC[6]), U1.L8 (VCC[6]), U1.L9 (VCC[6]), U1.L10 (VCC[6])
/PWR1V1EN: R54.2, U6.1 (EN), U7.5 (PG)
/PWR1V35: C1.2, C11.2, C37.1, C38.1, FB3.2, FB4.2, L1.2, R28.1, R34.1, TP3.1, U1.H11 (VCCIO2[2]), U1.J11 (VCCIO2[2]), U1.K11 (VCCIO3[2]), U1.L11 (VCCIO3[2])
/PWR2V5: C4.2, C50.1, U1.G11 (VCCAUX[2]), U1.L7 (VCCAUX[2]), U8.5 (OUT)
/PWR3V3: C2.2, C6.2, C7.2, C8.2, C9.2, C32.1, C33.1, C43.1, C46.1, C49.1, C53.1, C54.1, D7.1 (A), J4.4 (VDD), L3.2, MMOD1.6 (VCC), R1.1, R2.1, R3.1, R4.1, R11.1, R12.1, R20.1, R21.1, R22.1, R23.1, R24.1, R25.1, R26.1, R27.1, R31.1, R32.1, R57.1, R59.1, TP5.1, U1.F6 (VCCIO0[2]), U1.F7 (VCCIO0[2]), U1.F10 (VCCIO1[2]), U1.F11 (VCCIO1[2]), U1.H6 (VCCIO7[2]), U1.H7 (VCCIO7[2]), U1.J6 (VCCIO6[2]), U1.J7 (VCCIO6[2]), U1.L6 (VCCIO8), U8.1 (IN), U8.3 (EN), Y1.1 (INH), Y1.4 (VCC)
/PWR5V0: C15.1, C36.1, C44.1, C45.1, D11.1 (A1), FB1.1, FB2.1, J5.18 (+5V), R54.1, TP1.1, U3.1 (EN), U3.4 (VIN), U6.4 (VIN), U7.1 (EN), U7.4 (VIN)
/PWR5V0UF: D3.1 (A1), FB1.2, J1.A4 (VBUS), J1.A9 (VBUS), J1.B4 (VBUS), J1.B9 (VBUS), JTAG1.5
/RESET: R9.1, U1.M8 (PB15B/-/DOUT/CSON)
/SD_CD: R24.2, R30.1, U1.A5 (PT18A/+)
/SD_DAT1: J4.8 (DAT1), R25.2, U1.B5 (PT15B/-)
/SD_DAT2: J4.1 (DAT2), R26.2, U1.A2 (PT4A/+/ULC_GPLL1T_IN)
/SD_MISO: J4.7 (DAT0), R20.2, U1.A4 (PT6B/-)
/SD_MOSI: J4.3 (CMD), R22.2, U1.A3 (PT6A/+)
/SD_SCK: J4.5 (CLK), R21.2, U1.B4 (PT11B/-)
/SD_SS: J4.2 (DAT3/CD), R23.2, U1.B3 (PT4B/-/ULC_GPLL1C_IN)
/UART_RX: J3.2, U1.J1 (PL32A/+/PCLKT7_1/HS/LDQ29)
/UART_TX: J3.1, U1.J2 (PL32B/-/PCLKC7_1/HS/LDQ29)
/USB0_CONN_DN: D2.1 (A1), J1.A7 (DN1), J1.B7 (DN2), R8.1
/USB0_CONN_DP: D1.1 (A1), J1.A6 (DP1), J1.B6 (DP2), R6.2, R7.1
/USB0_DN: R8.2, U1.R6 (PB4B/-/D6/IO6)
/USB0_DP: R7.2, U1.T6 (PB4A/+/D7/IO7)
/USB0_DP_PU: R6.1, U1.R7 (PB6A/+/D5/MISO2/IO5)
/USB1_CONN_DN: D5.1 (A1), J2.2 (D-), R14.1, R16.1
/USB1_CONN_DP: D4.1 (A1), J2.3 (D+), R13.1, R15.1
/USB1_DN: R14.2, U1.B2 (PL11B/-/ULC_GPLL0C_IN/HS/LDQ17)
/USB1_DP: R13.2, U1.B1 (PL11A/+/ULC_GPLL0T_IN/HS/LDQ17)
/VIDEO_C: D10.2 (A2), J6.S, R45.2
/VIDEO_D0: R40.1, U1.M4 (PL44C/+/LDQ41)
/VIDEO_D1: R41.1, U1.P3 (PL59B/-/HS/LDQ65)
/VIDEO_D2: R42.1, U1.M5 (PL65C/+/LDQ65)
/VIDEO_D3: R43.1, U1.P2 (PL41B/-/HS/LDQSN41)
GND: C1.1, C2.1, C3.1, C4.1, C5.1, C6.1, C7.1, C8.1, C9.1, C10.1, C11.1, C12.1, C13.1, C14.1, C15.2, C16.2, C17.2, C18.2, C19.2, C20.2, C21.2, C22.2, C23.2, C24.2, C25.2, C26.2, C27.2, C28.2, C29.2, C30.2, C31.2, C32.2, C33.2, C34.2, C35.2, C36.2, C38.2, C39.2, C40.2, C43.2, C44.2, C45.2, C46.2, C47.2, C50.2, C51.2, C52.2, C53.2, C54.2, D1.2 (A2), D2.2 (A2), D3.2 (A2), D4.2 (A2), D5.2 (A2), D6.2 (A2), D8.1 (A1), D9.1 (A1), D10.1 (A1), D11.2 (A2), H1.1, H2.1, H3.1, H4.1, J1.A1 (GND), J1.A12 (GND), J1.B1 (GND), J1.B12 (GND), J1.S1 (SHIELD), J1.S2 (SHIELD), J1.S3 (SHIELD), J1.S4 (SHIELD), J2.4 (GND), J2.5 (Shield), J4.6 (VSS), J5.2 (D2S), J5.5 (D1S), J5.8 (D0S), J5.11 (CKS), J5.17 (GND), J5.S1 (SH), J5.S2 (SH), J5.S3 (SH), J5.S4 (SH), J6.R2, JTAG1.6, MMOD1.5 (GND), R5.2, R10.2, R15.2, R16.2, R17.2, R29.2, R33.2, R35.2, R56.2, R58.2, SW1.2, U1.A1 (GND[27]), U1.A16 (GND[27]), U1.D2 (GND[27]), U1.D15 (GND[27]), U1.F8 (GND[27]), U1.F9 (GND[27]), U1.G8 (GND[27]), U1.G10 (GND[27]), U1.H1 (GND[27]), U1.H8 (GND[27]), U1.H9 (GND[27]), U1.H10 (GND[27]), U1.H16 (GND[27]), U1.J8 (GND[27]), U1.J9 (GND[27]), U1.J10 (GND[27])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
unnamed: C16.1, D6.1 (A1), FB2.2, J2.1 (VBUS)
unnamed: C24.1, R18.1, R19.1
unnamed: C37.2, R34.2, R35.1, U3.6 (FB)
unnamed: C39.1, C41.2, R38.2
unnamed: C40.1, C42.2, R39.2
unnamed: C48.2, R55.2, R56.1, U6.6 (FB)
unnamed: C49.2, R57.2, R58.1, U7.6 (FB)
unnamed: D7.2 (BK), R44.1
unnamed: D7.3 (RK), R36.1
unnamed: D7.4 (GK), R37.1
unnamed: J1.A5 (CC1), R5.1
unnamed: J1.B5 (CC2), R10.1
unnamed: J4.9 (DET_B), R30.2
unnamed: L1.1, U3.3 (SW)
unnamed: L2.1, U6.3 (SW)
unnamed: L3.1, U7.3 (SW)
unnamed: R40.2, R41.2, R42.2, R43.2, R45.1

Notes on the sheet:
N O I R
PWR3V3 COMES UP FIRST FOR MASTER SPI MODE, ECP5 DATASHEET SECTION 3.5
0.6 * (1 + (210/47)) = 3.28
MMOD has a 10K pull-up on CSPI_SS
0.6 * (1 + (100/120)) = 1.099
0.6 * (1 + (150/120)) = 1.35

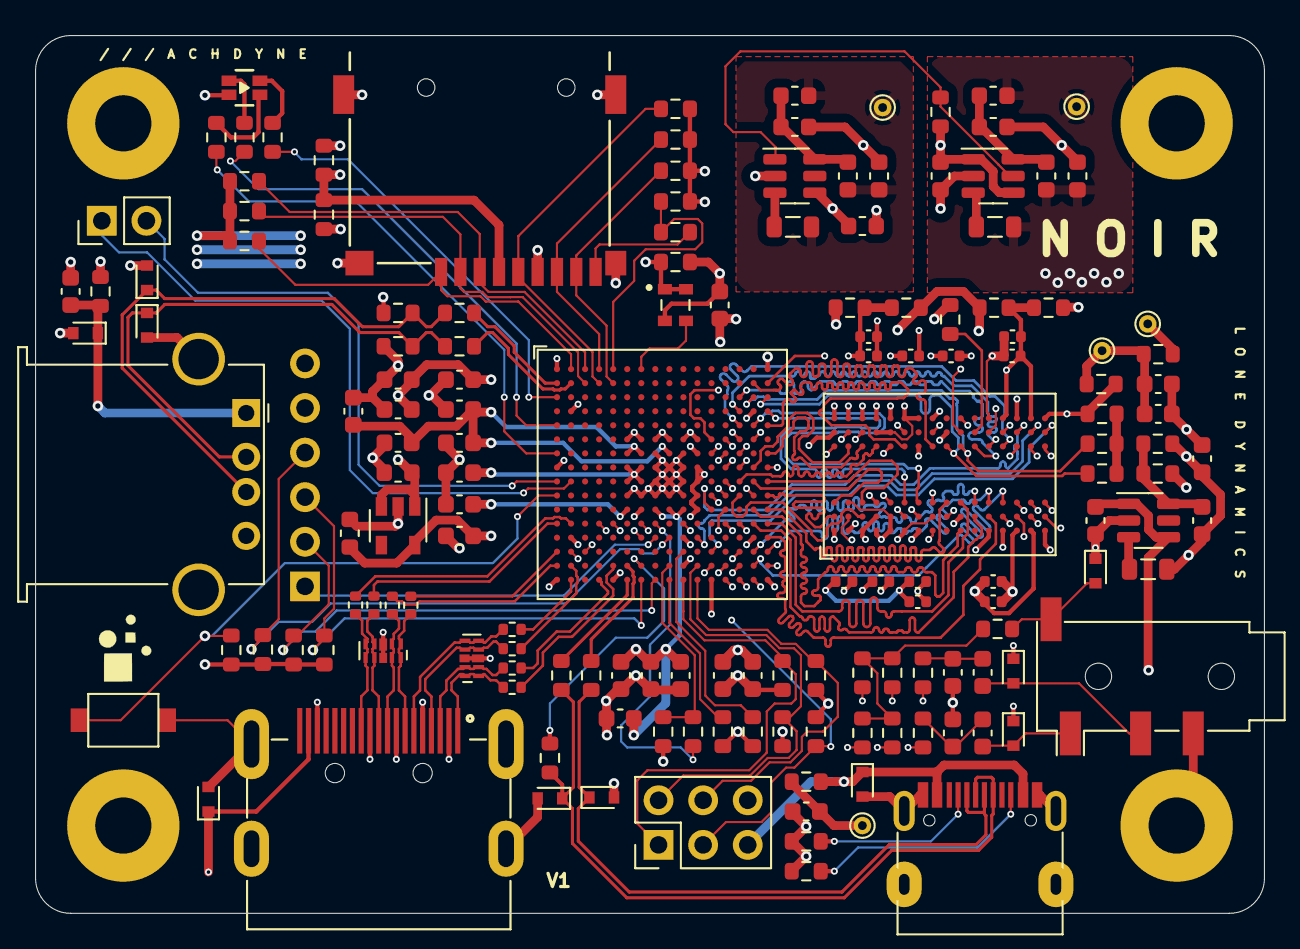
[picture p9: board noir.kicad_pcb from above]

Board: 6 copper layers, 70.0 x 50.0 mm, 158 parts (1 on the bottom side), 139 nets.

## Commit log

2022-12-30 add schematics
2023-01-06 use sd mode instead of spi mode for sdcard
2023-02-05 update case
    [noir.scad]
2023-05-07 add pcb
    [noir.kicad_pcb, noir.kicad_sch]

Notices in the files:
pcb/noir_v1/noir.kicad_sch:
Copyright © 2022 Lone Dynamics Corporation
